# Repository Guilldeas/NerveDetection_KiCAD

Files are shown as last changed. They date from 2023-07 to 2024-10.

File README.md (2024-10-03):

### Content

This repo stores KiCAD files for the development of a low noise preamplifier employing the gradiometer technique. Some symbols where custom made for the schematic and were provided on the Samac_Sys folder. User must add this folder to the KiCAD library path list to correctly visualize the schematics.

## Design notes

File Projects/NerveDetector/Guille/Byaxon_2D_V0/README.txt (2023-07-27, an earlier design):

This project aims to replicate Arturos project for a set of 2 sensors + one shared reference.

Additionaly it implements a way to correct offset voltage on the input stage by menas of a voltage divider and a voltage follower.

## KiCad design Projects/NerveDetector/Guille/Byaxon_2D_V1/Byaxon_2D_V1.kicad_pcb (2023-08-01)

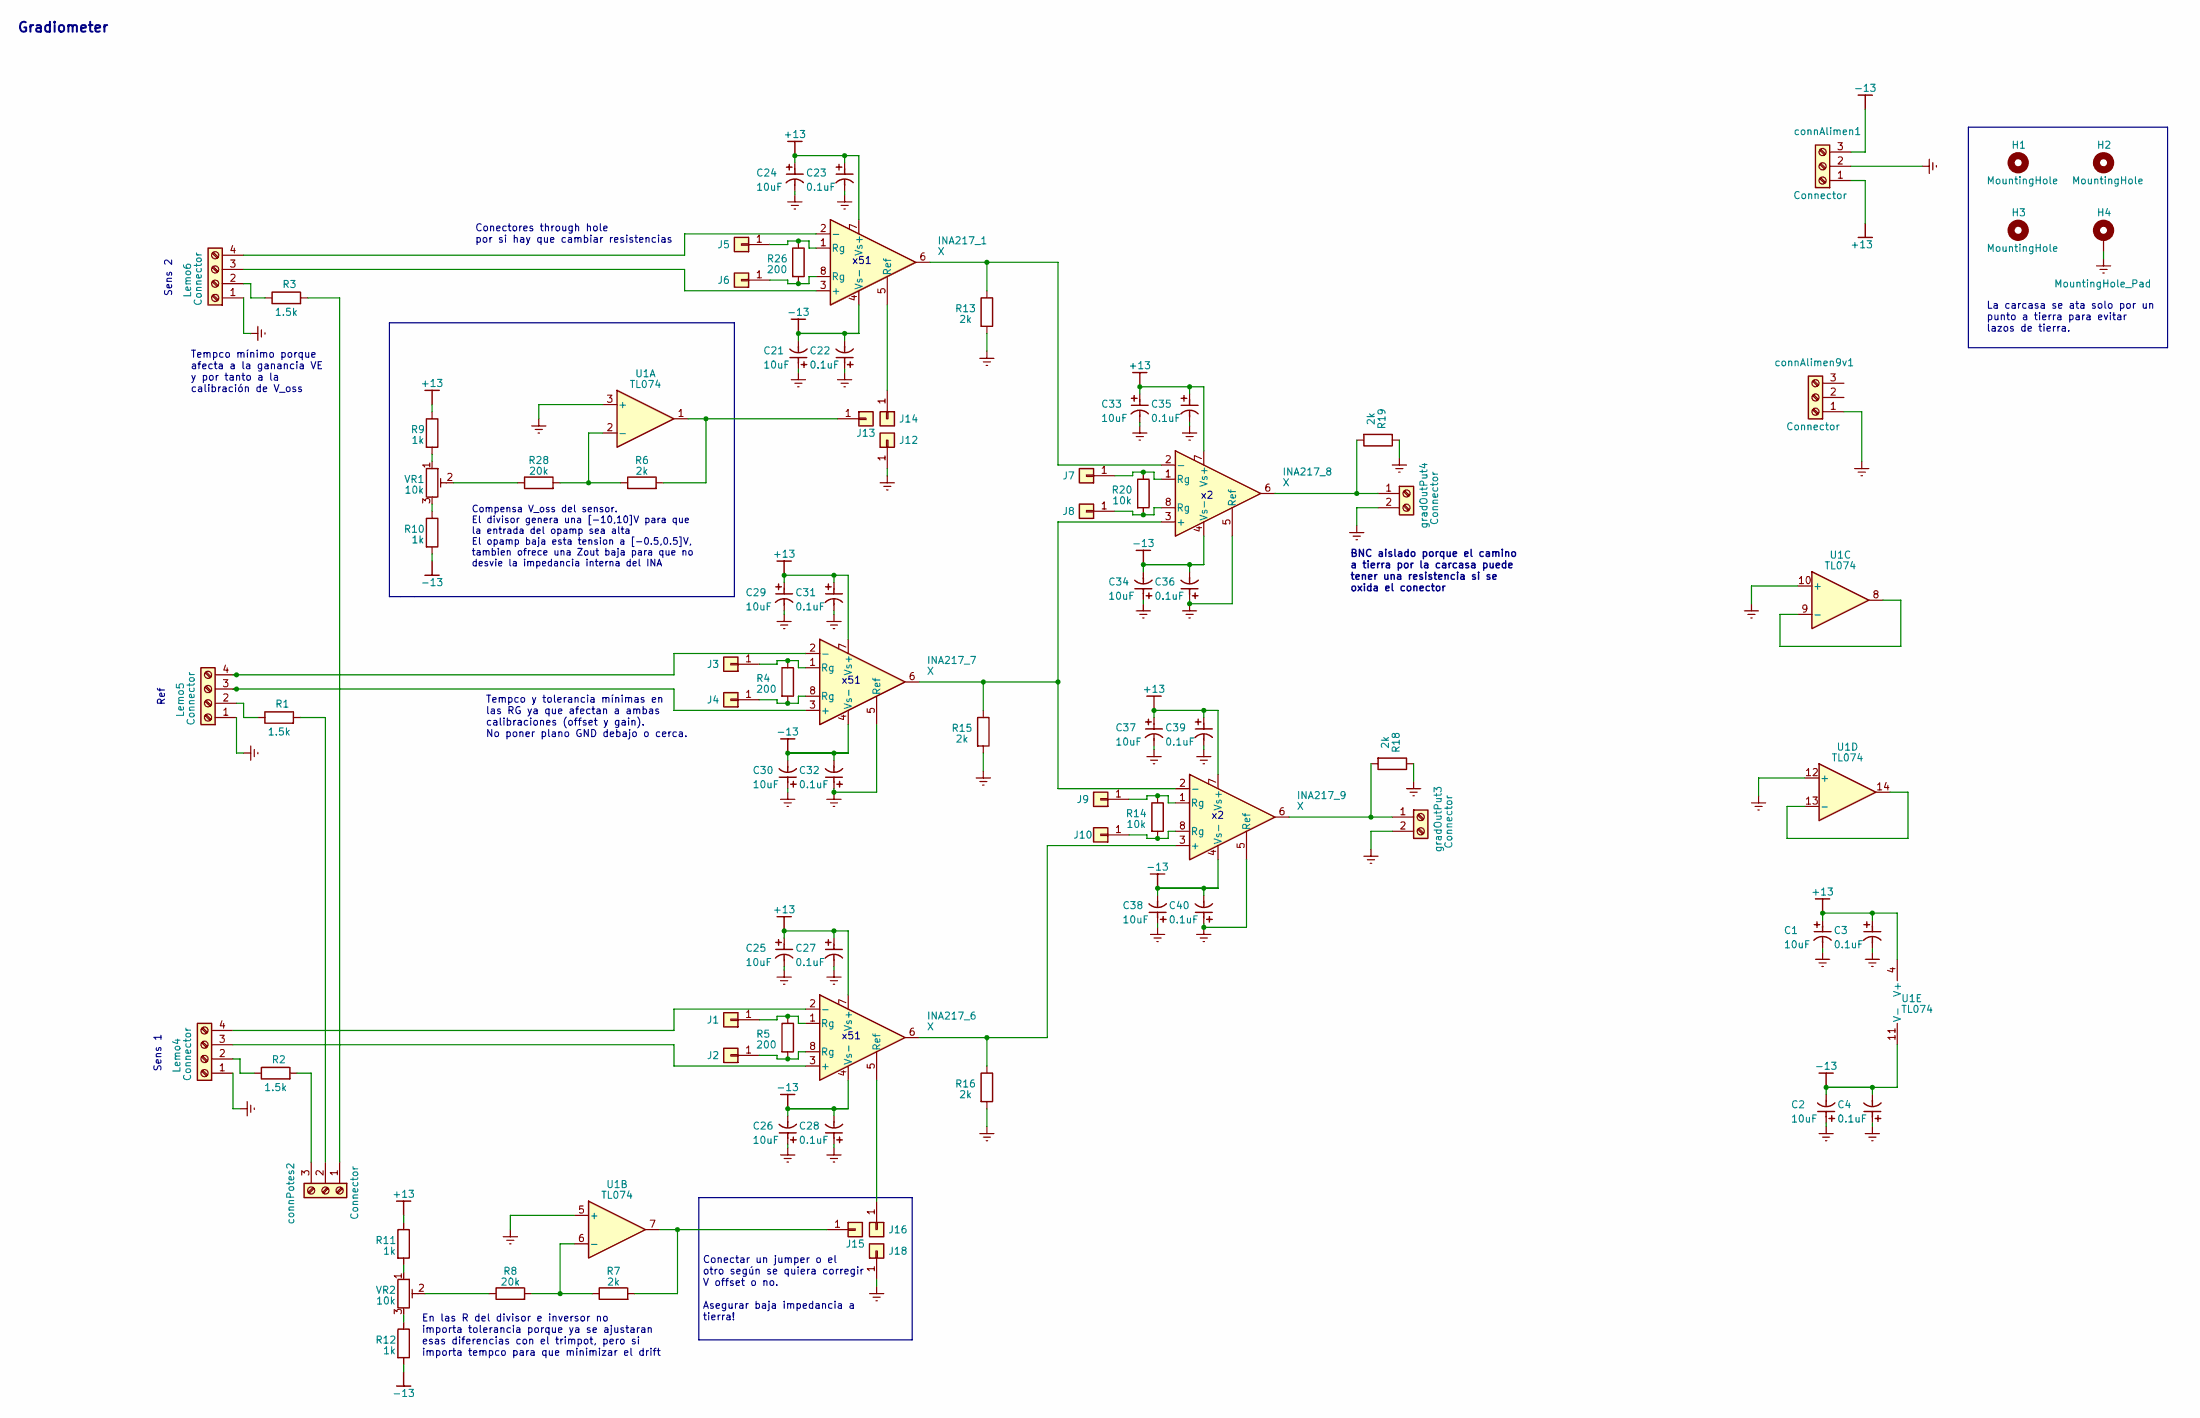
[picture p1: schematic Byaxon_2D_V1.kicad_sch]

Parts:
C1, C2, C21, C24, C25, C26, C29, C30, C33, C34, C37, C38: 10uF; CP_EIA-7132-20_AVX-U_Pad2.72x3.50mm_HandSolder
C3, C4, C22, C23, C27, C28, C31, C32, C35, C36, C39, C40: 0.1uF; CP_EIA-3216-10_Kemet-I_Pad1.58x1.35mm_HandSolder
H1, H2, H3: MountingHole; MountingHole_3.2mm_M3
H4: MountingHole_Pad; MountingHole_3.2mm_M3_DIN965_Pad
INA217_1, INA217_7, INA217_8, INA217_9: X; DIP-8_W7.62mm_Acid_Etch_Limitations
INA217_6: X; DIP-8_W7.62mm
J1, J2, J3, J4, J5, J6, J7, J8, J9, J10, J12, J13, J14, J15, J16, J18: Pin_D0.7mm_L6.5mm_W1.8mm_FlatFork
Lemo4, Lemo5, Lemo6: Connector; TerminalBlock_Phoenix_MPT-0,5-4-2.54_1x04_P2.54mm_Horizontal
R1, R2, R3: 1.5k; ERJ1T__2512_; Mouser Part Number 667-ERJ-1TNF1501U
R4, R5, R26: 200; RESC3016X65N; Mouser Part Number 708-RNCF1206TKY200R
R6, R7: 2k; R_0402_1005Metric_Pad0.72x0.64mm_HandSolder_Acid_Etch_Limit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; Mouser Part Number 667-ERA-2ARC202X
R8, R28: 20k; R_0402_1005Metric_Pad0.72x0.64mm_HandSolder_Acid_Etch_Limit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
R9, R10, R11, R12: 1k; RESC1608X60N; Mouser Part Number 754-RR0816P-102D
R13, R15, R16, R18, R19: 2k; RESC1005X40N_Acid_Etch_Limitations; Mouser Part Number 660-RK73H1ETTP2001F
R14, R20: 10k; RESC3016X65N; Mouser Part Number 708-RNCF1206TKY200R
U1: TL074; DIP794W53P254L1930H508Q14N_Acid_Etch_Limitations; Manufacturer_Part_Number TL074CN
VR1, VR2: 10k; 3362P_1_Acid_Etch_Limitations; Mouser Part Number 652-3362P-1-103LF
connAlimen1, connAlimen9v1: Connector; TerminalBlock_Phoenix_MPT-0,5-3-2.54_1x03_P2.54mm_Horizonta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
connPotes2: Connector; TerminalBlock_Phoenix_MPT-0,5-3-2.54_1x03_P2.54mm_Horizonta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
gradOutPut3, gradOutPut4: Connector; TerminalBlock_Phoenix_MPT-0,5-2-2.54_1x02_P2.54mm_Horizonta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

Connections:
+13: C1.2, C3.2, C23.2, C24.2, C25.2, C27.2, C29.2, C31.2, C33.2, C35.2, C37.2, C39.2, INA217_1.7 (Vs+), INA217_6.7 (Vs+), INA217_7.7 (Vs+), INA217_8.7 (Vs+), INA217_9.7 (Vs+), R9.1, R11.1, U1.4 (V+), connAlimen1.1
-13: C2.1, C4.1, C21.1, C22.1, C26.1, C28.1, C30.1, C32.1, C34.1, C36.1, C38.1, C40.1, INA217_1.4 (Vs-), INA217_6.4 (Vs-), INA217_7.4 (Vs-), INA217_8.4 (Vs-), INA217_9.4 (Vs-), R10.2, R12.2, U1.11 (V-), connAlimen1.3
Earth: C1.1, C2.2, C3.1, C4.2, C21.2, C22.2, C23.1, C24.1, C25.1, C26.2, C27.1, C28.2, C29.1, C30.2, C31.1, C32.2, C33.1, C34.2, C35.1, C36.2, C37.1, C38.2, C39.1, C40.2, H4.1, INA217_7.5 (Ref), INA217_8.5 (Ref), INA217_9.5 (Ref), J12.1, J18.1, Lemo4.1, Lemo5.1, Lemo6.1, R13.2, R15.2, R16.2, R18.1, R19.1, U1.3 (+), U1.5 (+), U1.10 (+), U1.12 (+), connAlimen1.2, connAlimen9v1.1, gradOutPut3.2, gradOutPut4.2
unnamed: INA217_1.3 (+), Lemo6.3
unnamed: INA217_1.2 (-), Lemo6.4
unnamed: INA217_1.5 (Ref), J14.1
unnamed: INA217_6.3 (+), Lemo4.3
unnamed: INA217_6.2 (-), Lemo4.4
unnamed: INA217_6.5 (Ref), J16.1
unnamed: INA217_7.3 (+), Lemo5.3
unnamed: INA217_7.2 (-), Lemo5.4
unnamed: INA217_7.6, INA217_8.3 (+), INA217_9.2 (-), R15.1
unnamed: INA217_1.6, INA217_8.2 (-), R13.1
unnamed: INA217_6.6, INA217_9.3 (+), R16.1
unnamed: INA217_6.1 (Rg), J1.1, R5.1
unnamed: INA217_6.8 (Rg), J2.1, R5.2
unnamed: INA217_7.1 (Rg), J3.1, R4.1
unnamed: INA217_7.8 (Rg), J4.1, R4.2
unnamed: INA217_1.1 (Rg), J5.1, R26.1
unnamed: INA217_1.8 (Rg), J6.1, R26.2
unnamed: INA217_8.1 (Rg), J7.1, R20.1
unnamed: INA217_8.8 (Rg), J8.1, R20.2
unnamed: INA217_9.1 (Rg), J9.1, R14.1
unnamed: INA217_9.8 (Rg), J10.1, R14.2
unnamed: J13.1, R6.2, U1.1
unnamed: J15.1, R7.2, U1.7
unnamed: Lemo4.2, R2.1
unnamed: Lemo5.2, R1.1
unnamed: Lemo6.2, R3.1
unnamed: R8.1, VR2.2
unnamed: R9.2, VR1.1
unnamed: R10.1, VR1.3
unnamed: R11.2, VR2.1
unnamed: R12.1, VR2.3
unnamed: R28.1, VR1.2
unnamed: R6.1, R28.2, U1.2 (-)
unnamed: R7.1, R8.2, U1.6 (-)
unnamed: U1.8, U1.9 (-)
unnamed: U1.13 (-), U1.14
unnamed: R3.2, connPotes2.1
unnamed: R1.2, connPotes2.2
unnamed: R2.2, connPotes2.3
unnamed: INA217_9.6, R18.2, gradOutPut3.1
unnamed: INA217_8.6, R19.2, gradOutPut4.1

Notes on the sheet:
Gradiometer
Conectar un jumper o el otro según se quiera corregir V offset o no. Asegurar baja impedancia a tierra!
Compensa V_oss del sensor. El divisor genera una [-10,10]V para que la entrada del opamp sea alta El opamp baja esta tension a [-0.5,0.5]V, tambien ofrece una Zout baja para que no desvie la impedancia interna del INA
Sens 2
La carcasa se ata solo por un punto a tierra para evitar lazos de tierra.
Conectores through hole por si hay que cambiar resistencias
x51
Sens 1
BNC aislado porque el camino a tierra por la carcasa puede tener una resistencia si se oxida el conector
Ref
Tempco mínimo porque afecta a la ganancia VE y por tanto a la calibración de V_oss
Tempco y tolerancia mínimas en las RG ya que afectan a ambas calibraciones (offset y gain). No poner plano GND debajo o cerca.
En las R del divisor e inversor no importa tolerancia porque ya se ajustaran esas diferencias con el trimpot, pero si importa tempco para que minimizar el drift

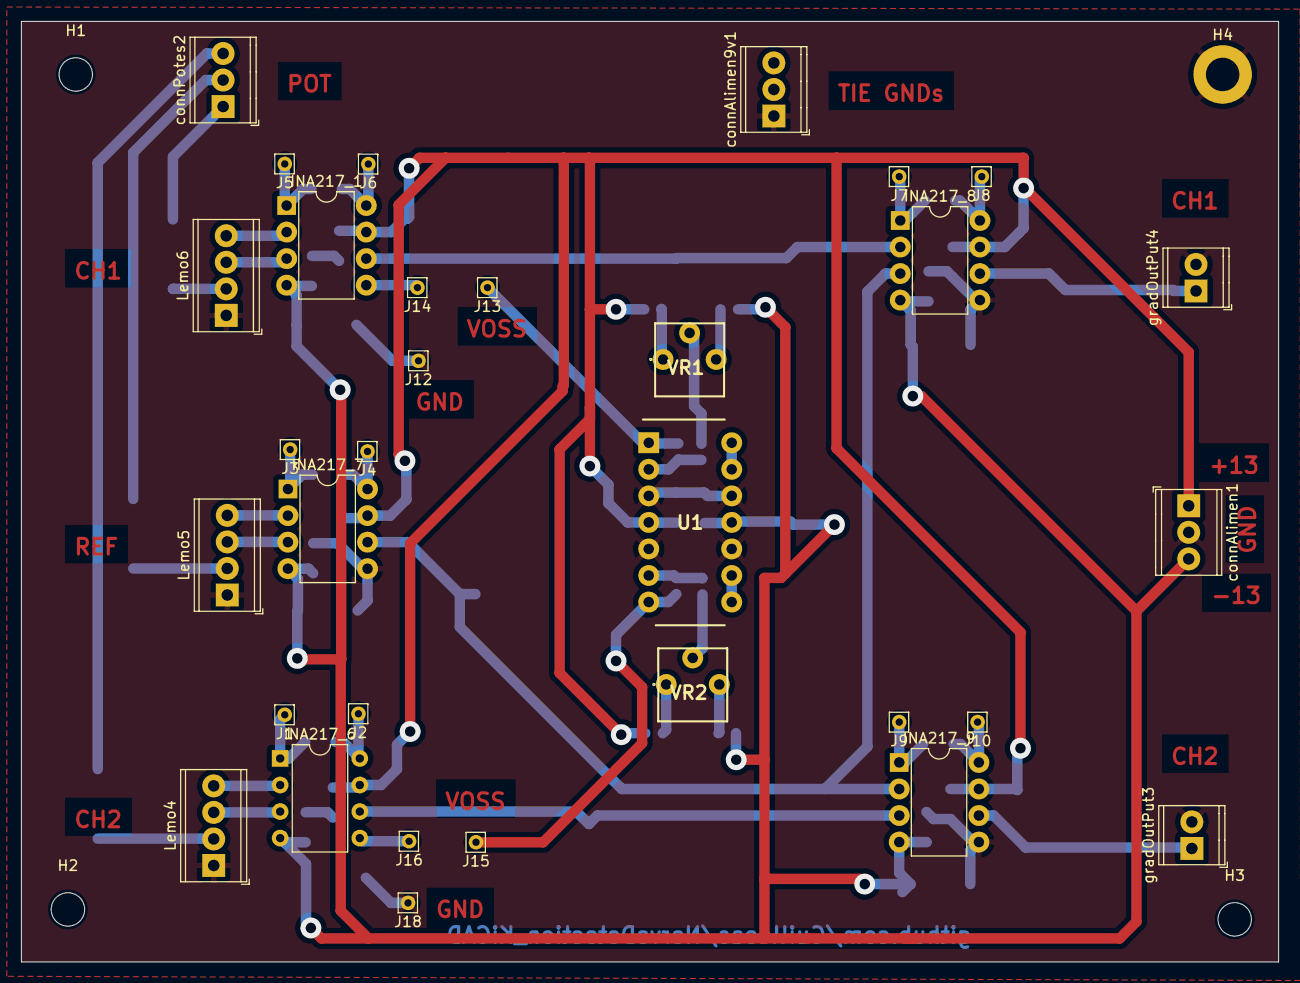
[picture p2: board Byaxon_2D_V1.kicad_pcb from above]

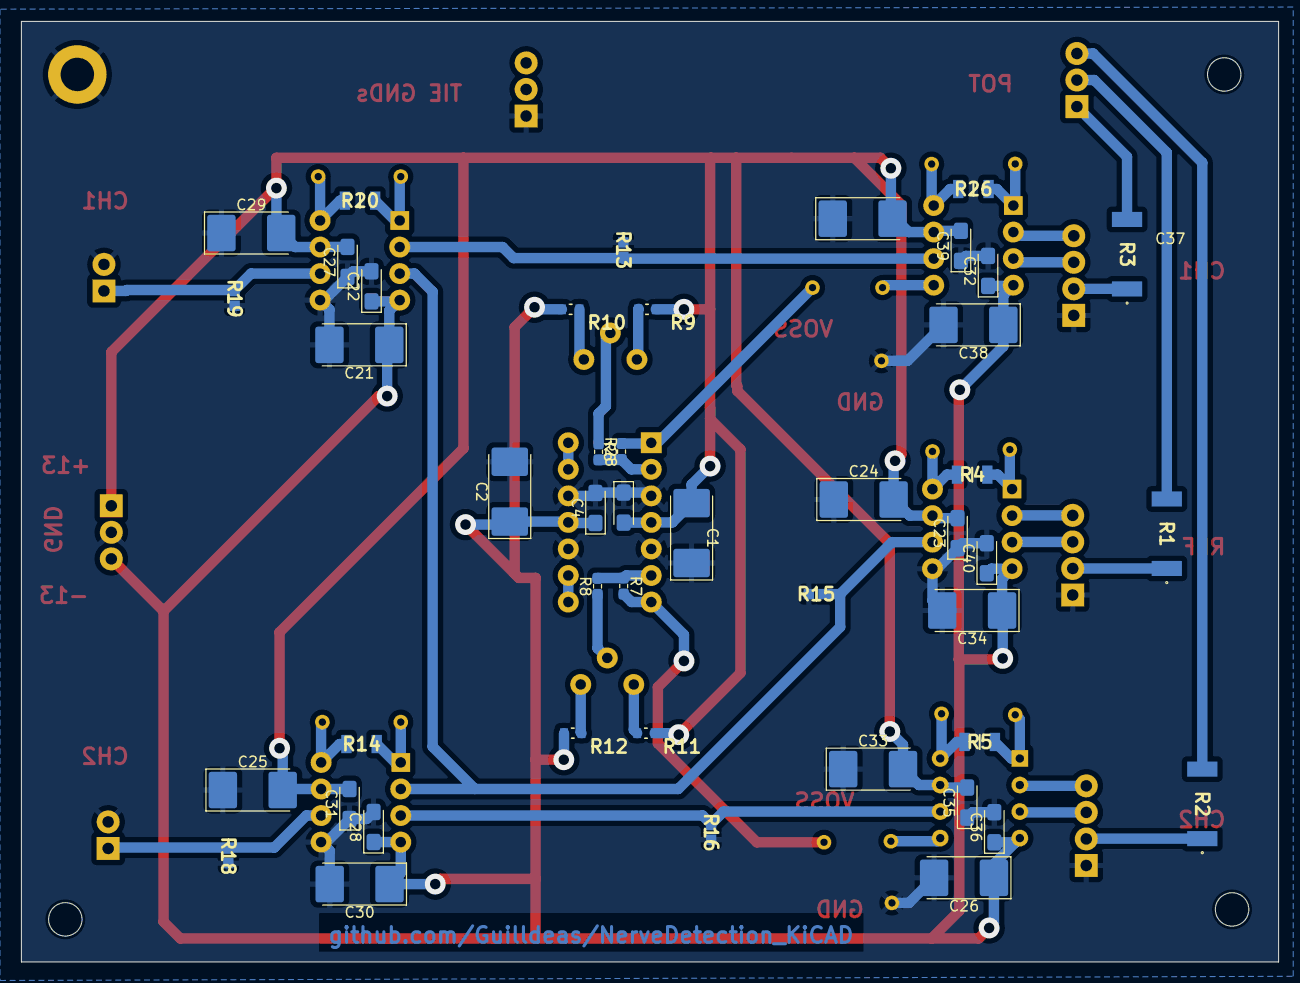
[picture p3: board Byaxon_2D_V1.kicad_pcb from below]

Board: 2 copper layers, 120.3 x 90.0 mm, 81 parts (45 on the bottom side), 44 nets.

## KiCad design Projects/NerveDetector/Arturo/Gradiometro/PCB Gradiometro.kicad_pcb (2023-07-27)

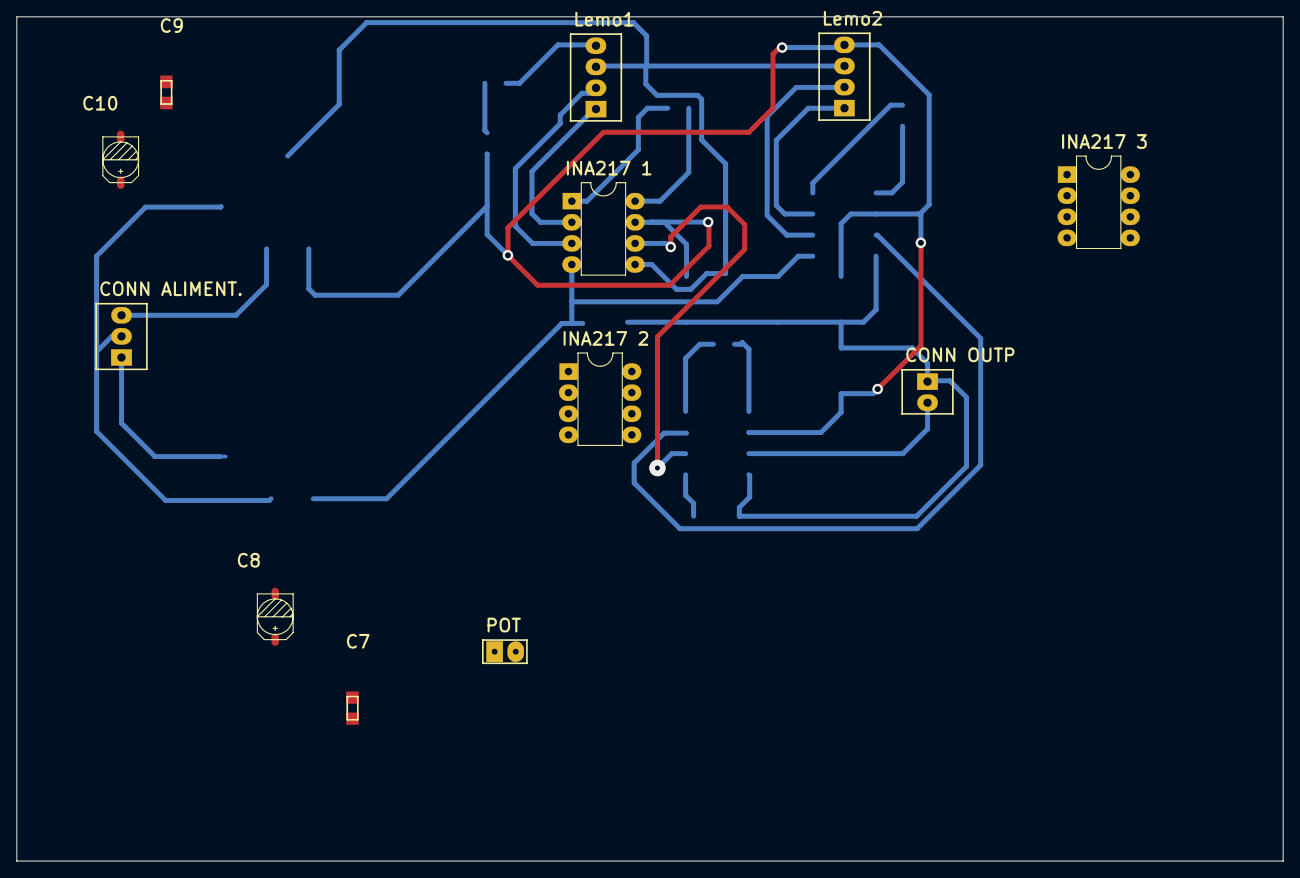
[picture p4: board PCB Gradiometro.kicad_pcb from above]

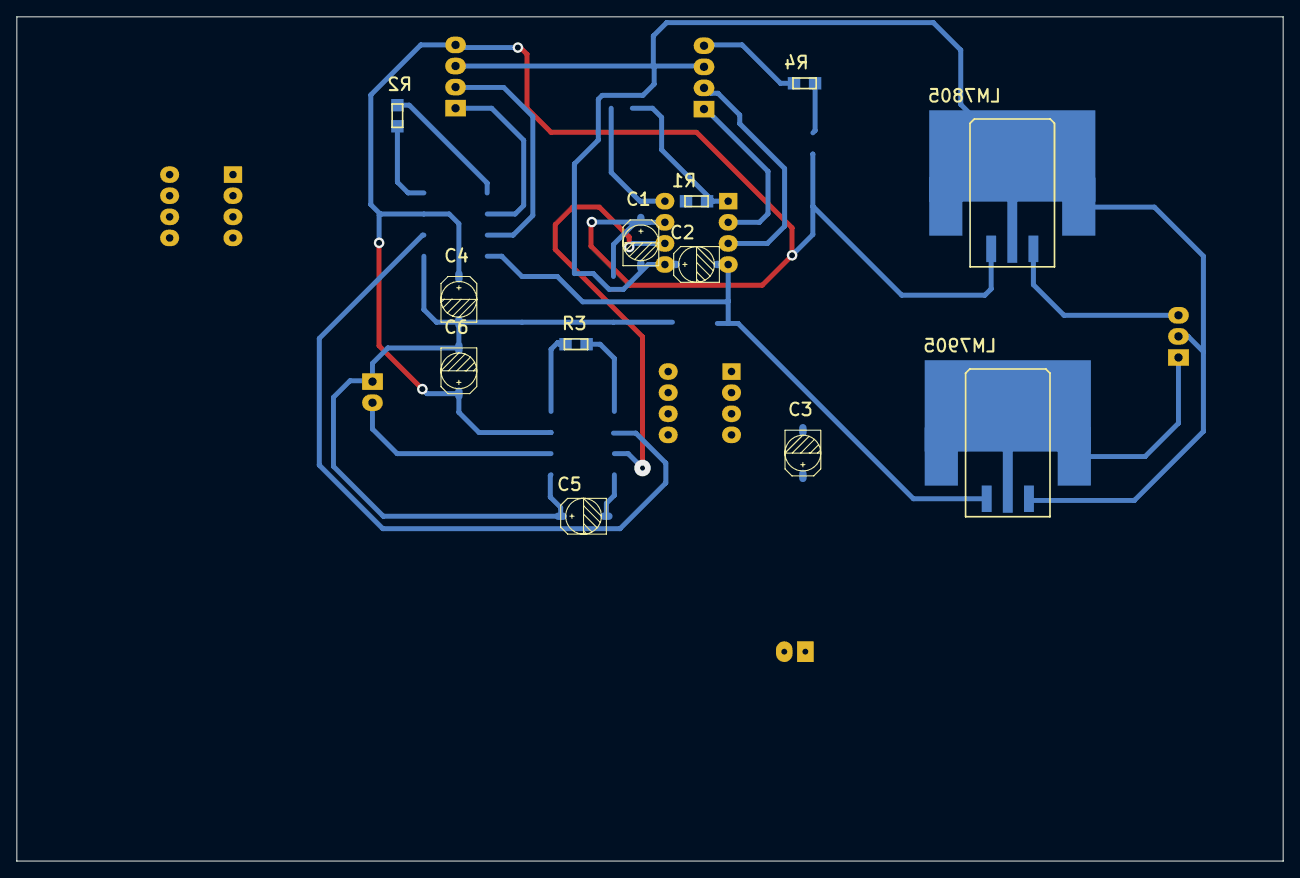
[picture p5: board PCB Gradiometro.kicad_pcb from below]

Board: 2 copper layers, 152.4 x 101.6 mm, 24 parts (12 on the bottom side), 20 nets.

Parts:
C1, C4, C6: 10 uF; C SMD Electrolytic
C2, C3, C5: 10uF; C SMD Electrolytic
C7: 2.2uF; SMD0805
C8: 1uF; C SMD Electrolytic
C9: 0.33uF; SMD0805
C10: 0.1uF; C SMD Electrolytic
CONN ALIMENT.: Connector; Bloque.Ter. 3
CONN OUTP: Connector; Bloque.Ter. 2
INA217 1, INA217 2, INA217 3: X; DIP 8
LM7805: LM78XX; 7805 Smd
LM7905: LM78XX; 7905 SMD
Lemo1, Lemo2: Connector; Bloque.Ter. 4
POT: Connector; Tira 2 Pines
R1, R2: 204 Ohm; SMD0805
R3: 111 Ohm; SMD0805
R4: Value; SMD0805

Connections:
+5: C1.2, C4.2, C6.2, C10.2, INA217 1.7, INA217 2.7, INA217 3.7, LM7805.Vout, Lemo2.4, POT.2
-5: C2.1, C3.1, C5.1, C8.1, INA217 1.4, INA217 2.4, INA217 3.4, LM7905.Vout
GND: C1.1, C2.2, C3.2, C4.1, C5.2, C6.1, C7.1, C8.2, C9.1, C10.1, CONN ALIMENT..2, CONN OUTP.1, INA217 1.5, INA217 2.5, INA217 3.5, LM7805.GND, LM7905.GND, Lemo1.3, Lemo2.3
NetC7_2: C7.2, CONN ALIMENT..1, LM7905.Vin
NetC9_2: C9.2, CONN ALIMENT..3, LM7805.Vin
NetCONN OUTP_2: CONN OUTP.2, INA217 3.6
NetINA217 1_1: INA217 1.1, R1.1
NetINA217 1_2: INA217 1.2, Lemo1.1
NetINA217 1_3: INA217 1.3, Lemo1.2
NetINA217 1_6: INA217 1.6, INA217 3.3
NetINA217 1_8: INA217 1.8, R1.2
NetINA217 2_1: INA217 2.1, R2.1
NetINA217 2_2: INA217 2.2, Lemo2.1
NetINA217 2_3: INA217 2.3, Lemo2.2
NetINA217 2_6: INA217 2.6, INA217 3.2
NetINA217 2_8: INA217 2.8, R2.2
NetINA217 3_1: INA217 3.1, R3.1
NetINA217 3_8: INA217 3.8, R3.2
NetLemo1_4: Lemo1.4, R4.2
NetPOT_1: POT.1, R4.1

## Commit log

2023-07-27 Got files properly sorted into folders
    [Byaxon_2D_V0.kicad_pcb, Byaxon_2D_V0.kicad_sch, Byaxon_2D_V1.kicad_pcb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]
2023-07-27 Solved problem with footprint libraries missing
    [Byaxon_2D_V1.kicad_pcb, Byaxon_2D_V1.kicad_sch]
2023-07-27 Layed out bigger edge cut, added jumper to Voss
    [Byaxon_2D_V1.kicad_pcb, Byaxon_2D_V1.kicad_sch]
2023-07-28 Changed jumpers + some layout
    [Byaxon_2D_V1.kicad_pcb, Byaxon_2D_V1.kicad_sch]
2023-07-28 Final commit of the day - Some layout
    [Byaxon_2D_V1.kicad_pcb, Byaxon_2D_V1.kicad_sch]
2023-07-31 Finished layout
    [Byaxon_2D_V1-Bottom Layer.gbr, Byaxon_2D_V1-Bottom Overlay.gbr, Byaxon_2D_V1-Bottom Paste.gbr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]
2023-07-31 Added link to projects github on the PCB
    [Byaxon_2D_V1.kicad_pcb]
2023-08-01 Added mounting holes
    [Byaxon_2D_V1.kicad_pcb, Byaxon_2D_V1.kicad_sch]
